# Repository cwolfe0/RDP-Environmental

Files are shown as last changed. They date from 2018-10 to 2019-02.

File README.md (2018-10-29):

# RDP-Environmental
This is a PCB designed in KiCad for the UAH SHC HELEN project's Radiation Detection Payload (RDP). This board is intended to gather environmental inupt including temperature, pressure and GPS.  This information is processed and saved and potentially shared with an external FPGA.
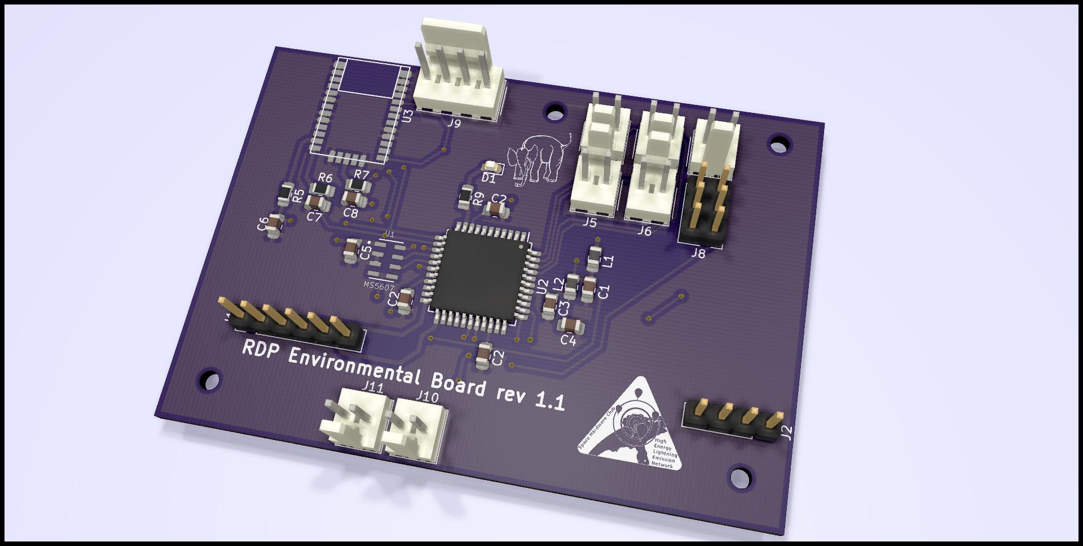
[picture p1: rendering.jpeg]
PCB Rendering in KiCad


The rendering above is a rough idea of what this payload will look like with some of its components installed.

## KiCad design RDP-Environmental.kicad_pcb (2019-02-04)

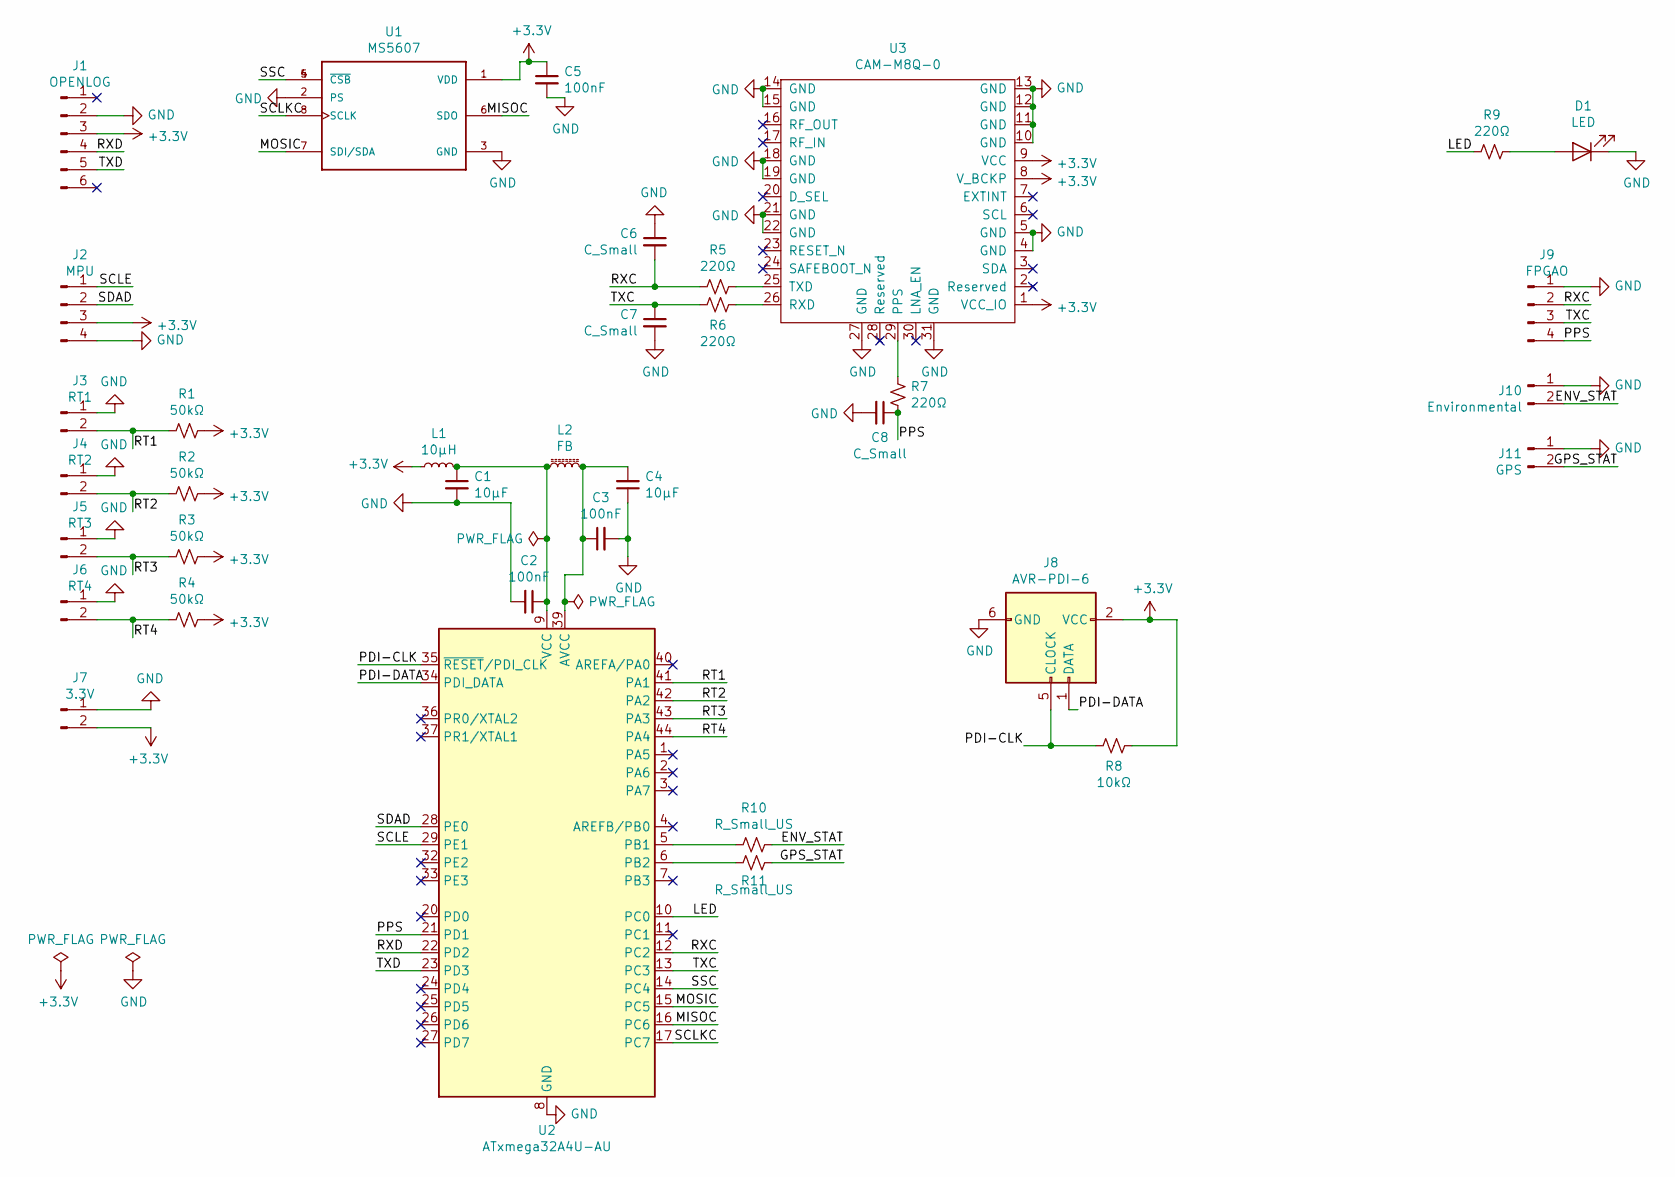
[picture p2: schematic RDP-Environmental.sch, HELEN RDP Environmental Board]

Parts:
C1, C4: 10μF; C_0805_2012Metric_Pad1.15x1.40mm_HandSolder
C2, C3, C5: 100nF; C_0805_2012Metric_Pad1.15x1.40mm_HandSolder
C6, C7, C8: C_Small; C_0805_2012Metric_Pad1.15x1.40mm_HandSolder
D1: LED; LED_0603_1608Metric
J1: OPENLOG; PinHeader_1x06_P2.54mm_Vertical
J2: MPU; PinHeader_1x04_P2.54mm_Vertical
J3: RT1; Molex_KK-254_AE-6410-02A_1x02_P2.54mm_Vertical
J4: RT2; Molex_KK-254_AE-6410-02A_1x02_P2.54mm_Vertical
J5: RT3; Molex_KK-254_AE-6410-02A_1x02_P2.54mm_Vertical
J6: RT4; Molex_KK-254_AE-6410-02A_1x02_P2.54mm_Vertical
J7: 3.3V; Molex_KK-254_AE-6410-02A_1x02_P2.54mm_Vertical
J8: AVR-PDI-6; PinHeader_2x03_P2.54mm_Vertical
J9: FPGAO; Molex_KK-254_AE-6410-04A_1x04_P2.54mm_Vertical
J10: Environmental; Molex_KK-254_AE-6410-02A_1x02_P2.54mm_Vertical
J11: GPS; Molex_KK-254_AE-6410-02A_1x02_P2.54mm_Vertical
L1: 10μH; L_0805_2012Metric_Pad1.15x1.40mm_HandSolder
L2: FB; L_0805_2012Metric_Pad1.15x1.40mm_HandSolder
R1, R2, R3, R4: 50kΩ; R_0805_2012Metric_Pad1.15x1.40mm_HandSolder
R5, R6, R7, R9: 220Ω; R_0805_2012Metric_Pad1.15x1.40mm_HandSolder
R8: 10kΩ; R_0805_2012Metric_Pad1.15x1.40mm_HandSolder
R10, R11: R_Small_US; R_0805_2012Metric_Pad1.15x1.40mm_HandSolder
U1: MS5607; SON125P300X500X100-8N
U2: ATxmega32A4U-AU; TQFP-44_10x10mm_P0.8mm
U3: CAM-M8Q-0; CAM-M8

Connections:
+3V3: C5.1, J1.3, J2.3, J7.2, J8.2 (VCC), L1.1, R1.1, R2.1, R3.1, R4.1, R8.2, U1.1 (VDD), U3.1 (VCC_IO), U3.8 (V_BCKP), U3.9 (VCC)
/ENV_STAT: J10.2, R10.1
/GPS_STAT: J11.2, R11.2
/LED: R9.2, U2.10 (PC0)
/MISOC: U1.6 (SDO), U2.16 (PC6)
/MOSIC: U1.7 (SDI/SDA), U2.15 (PC5)
/PDI-CLK: J8.5 (CLOCK), R8.1, U2.35 (~RESET~/PDI_CLK)
/PDI-DATA: J8.1 (DATA), U2.34 (PDI_DATA)
/PPS: C8.1, J9.4, R7.1, U2.21 (PD1)
/RT1: J3.2, R1.2, U2.41 (PA1)
/RT2: J4.2, R2.2, U2.42 (PA2)
/RT3: J5.2, R3.2, U2.43 (PA3)
/RT4: J6.2, R4.2, U2.44 (PA4)
/RXC: C6.2, J9.2, R5.2, U2.12 (PC2)
/RXD: J1.4, U2.22 (PD2)
/SCLE: J2.1, U2.29 (PE1)
/SCLKC: U1.8 (SCLK), U2.17 (PC7)
/SDAD: J2.2, U2.28 (PE0)
/SSC: U1.4 (~CSB~), U1.5 (~CSB~), U2.14 (PC4)
/TXC: C7.1, J9.3, R6.2, U2.13 (PC3)
/TXD: J1.5, U2.23 (PD3)
GND: C1.2, C2.2, C3.2, C4.1, C5.2, C6.1, C7.2, C8.2, D1.1 (K), J1.2, J2.4, J3.1, J4.1, J5.1, J6.1, J7.1, J8.6 (GND), J9.1, J10.1, J11.1, U1.2 (PS), U1.3 (GND), U2.8 (GND), U2.18 (GND), U2.30 (GND), U2.38 (GND), U3.4 (GND), U3.5 (GND), U3.10 (GND), U3.11 (GND), U3.12 (GND), U3.13 (GND), U3.14 (GND), U3.15 (GND), U3.18 (GND), U3.19 (GND), U3.21 (GND), U3.22 (GND), U3.27 (GND), U3.31 (GND); also elsewhere on the board
unnamed 22: C1.1, C2.1, L1.2, L2.1, U2.9 (VCC), U2.19 (VCC), U2.31 (VCC); also elsewhere on the board
unnamed: C3.1, C4.2, L2.2, U2.39 (AVCC)
unnamed: D1.2 (A), R9.1
unnamed: R5.1, U3.25 (TXD)
unnamed: R6.1, U3.26 (RXD)
unnamed: R7.2, U3.29 (PPS)
unnamed: R10.2, U2.5 (PB1)
unnamed: R11.1, U2.6 (PB2)

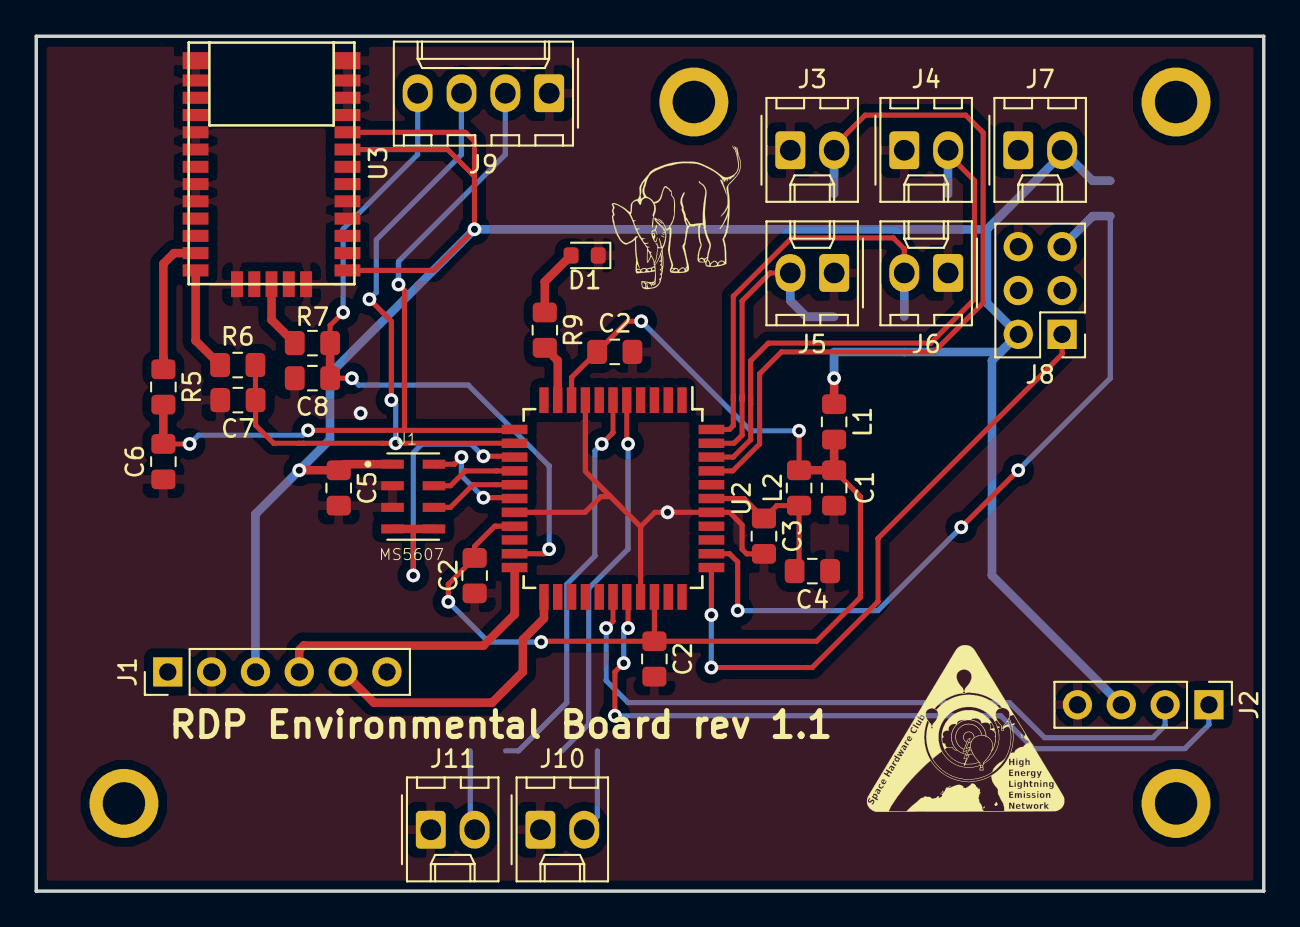
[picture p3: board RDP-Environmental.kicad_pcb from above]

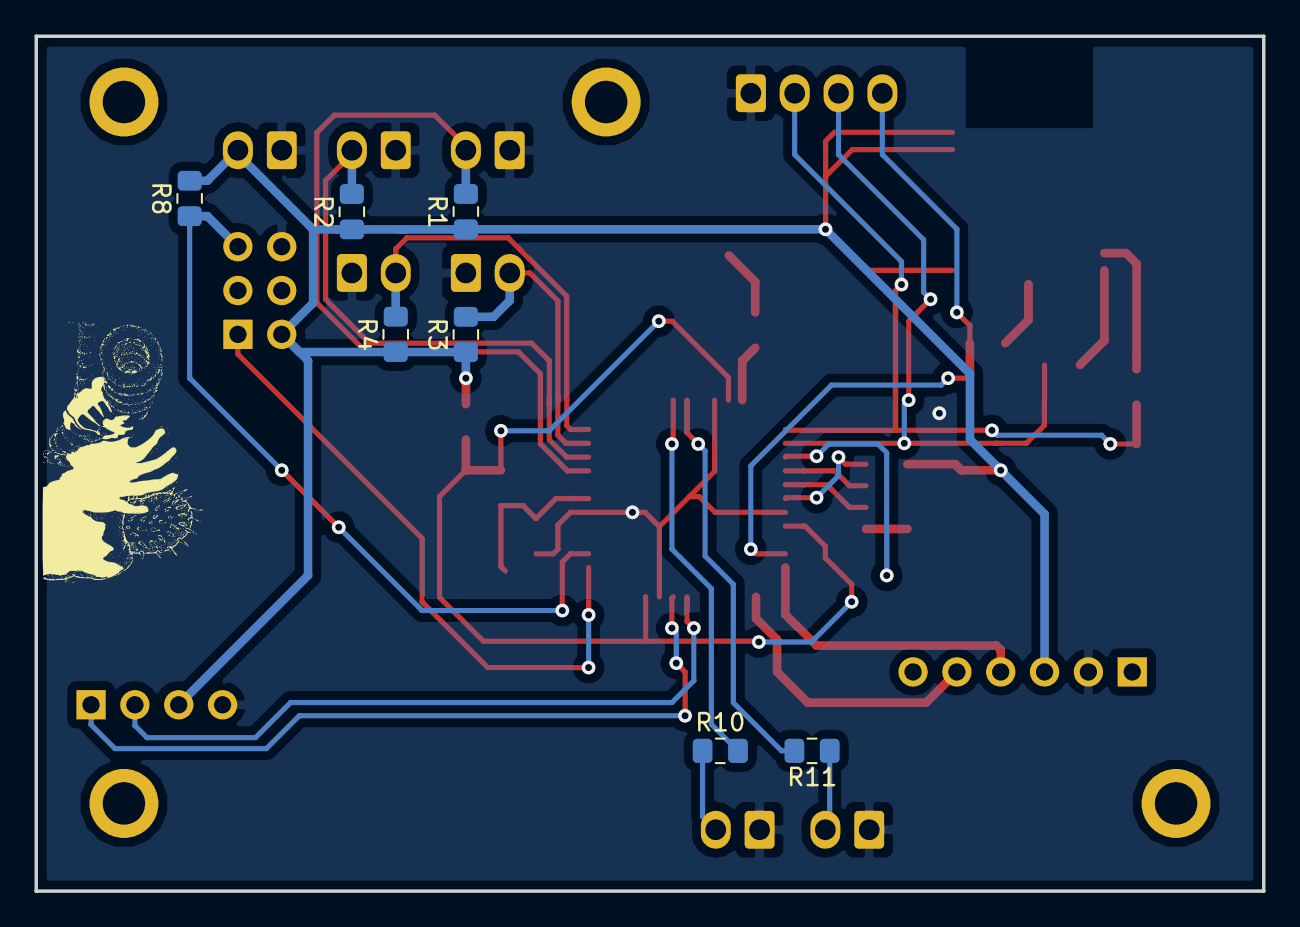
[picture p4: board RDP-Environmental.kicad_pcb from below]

Board: 2 copper layers, 71.1 x 49.5 mm, 38 parts (7 on the bottom side), 30 nets.

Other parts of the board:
C2#2, C2#3: 100nF; C_0805_2012Metric_Pad1.15x1.40mm_HandSolder

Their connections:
GND: C2#2.2, C2#3.2; also elsewhere on the board
unnamed 22: C2#2.1, C2#3.1; also elsewhere on the board

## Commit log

2018-10-30 Add GPS and groud to output for FPGA
    [RDP-Environmental-B.Cu.gbr, RDP-Environmental-B.Mask.gbr, RDP-Environmental-B.Paste.gbr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]
2018-11-01 Add dimensions to PCB CAD
    [RDP-Environmental.kicad_pcb]
2018-11-03 Fix MPU 9250 clearance
    [RDP-Environmental-B.Cu.gbl, RDP-Environmental-B.Mask.gbs, RDP-Environmental-B.Paste.gbp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]
2018-11-05 Fix thermistor resistance values
    [RDP-Environmental.sch]
2019-01-10 Fix drill files in GBR/Gerbers.zip. Increment rev number
    [RDP-Environmental-B.Cu.gbl, RDP-Environmental-B.Mask.gbs, RDP-Environmental-B.Paste.gbp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]
2019-02-02 Add status LED pins for GPS and general status
    [RDP-Environmental-B.Cu.gbl, RDP-Environmental-B.Mask.gbs, RDP-Environmental-B.Paste.gbp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]
2019-02-04 Make holes bigger
    [RDP-Environmental-B.Cu.gbl, RDP-Environmental-B.Mask.gbs, RDP-Environmental-B.Paste.gbp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]
